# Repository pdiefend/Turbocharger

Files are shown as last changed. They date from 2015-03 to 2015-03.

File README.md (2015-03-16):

# Turbocharger
Turbocharger started as a Google Code Project and is in the process of being migrated to GitHub.
Farewell old friend.

The Turbocharger Arduino motor driver is a motor driver designed to amplify the abilities for Arduino robot control. This driver board includes encoder counters, an on-board motor driver, and serial communication headers to be as adaptable as possible for projects needing small motors with encoders.

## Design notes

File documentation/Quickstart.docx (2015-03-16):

# Turbocharger DC Motor Driver

# Features and Ratings

- Dual DC motor driver
  - ST-L298P Quad H-Bridge Motor Driver
  - Up to 48V motors and up to 2A per motor.
  - Up to 4A if both channels are used together
  - If 1A or less current is used, no heat sink or forced air cooling necessary
- Dual Quadrature Encoder Inputs
  - LS/CSI LS7366R-S Serial Encoder Counter from US Digital
  - 32-bit reconfigurable quadrature encoder counters
  - SPI enabled to reduce microcontroller utilization
- Designed for Arduino Uno
  - All communications are designed for 5V. A 3.3V board may be used if the pins are 5V tolerant. MISO (digital pin 12) is a 5V output from the encoder counters and will damage a 3.3V board.

# Caution:

Before making connections:

1. Ensure your power supply is ABLE to have the Negative DC Output connected to the common ground for the system. There are some power supplies in the wild that create a neutral->ground fault when the negative output from the supply is connected to ground. The driver will force a common ground to all supplies.
2. Add an appropriate sized fuse between the positive terminal of the power supply and the driver board. The driver is able to handle 3A for 100us, more than this will destroy the driver. Ask for help in fuse sizing if you are inexperienced.
3. If the Motor voltage is greater than 12V, make sure the Vin_enable jumper is cleared to prevent damage to the Arduino.

Finally, check all connectors for potential shorts before applying power.

# Pin Connections to Arduino

## Motor Driver Arduino Pin-out

Description | Arduino Pin Number
Channel A Direction | 7
Channel A PWM | 9
Channel A Current Sense | A3
Channel B Direction | 8
Channel B PWM | 10
Channel B Current Sense | A2

## Quadrature Encoder Arduino Pin-out

Description | Arduino Pin Number
MOSI | 11 | Pins 11-13 are SPI for the Arduino
MISO | 12 | and are handled in the SPI Library
SCK | 13 | Do not use the pins
Encoder Counter 1 Select | 4
Encoder Counter 2 Select | 5
Counter Enable | 6
!LFLAG with pull-up resistor | 2

# Pin Connections to Peripherals

Headers for easier connection to communication buses and other microcontroller functions have been provided for your convince. These headers include Two Wire Interface (TWI; also known as I2C), Serial Peripheral Interface (SPI), Universal Asynchronous Receiver/Transmitter (UART), and finally two analog input enabled pins that are available in servo-standard pin-outs.

## SPI

The SPI communication bus can support one additional peripheral (or more if you are experienced). The SPI bus is shared with the LS7366R-S Quadrature Encoder Counters. Digital Pin 3 has been made available for use as a chip select pin for this peripheral and is available on this header. Please note that pin 3 is arranged next to Vdd and Ground such that pin 3 can also be used apart from SPI with a servo-standard pin-out. This was done such that pin 3, which is an interrupt-enabled pin on the Arduino Uno, can be used for am interrupt-enabled limit switch.

## UART

The UART communication bus is broken out above the SPI bus on the board. This is the hardware UART for the Arduino with no flow control or reset. This can be used if a peripheral needs Serial communications and the UART is not being used to talk to the computer. When programming through the USB port peripherals connected to this header must be disconnected.

## TWI

PLEASE NOTE: SDA and SCL on the TWI header are labelled incorrectly and should be swapped.

The TWI has been made available for users who need the I2C communication protocol. On R3 Arduino Unos these pins are available on the digital side, but on R2 Arduino Unos these pins are only available with the analog input pins. In the interests of keeping this board inclusive, the TWI header is connected to Analog Pins A4 and A5. With this, if additional analog pins past A0 and A1 are needed and no I2C is needed, these pins can be directly used as analog inputs. Also, since all analog input pins are digital enabled as well, these pins can serve digital functions too.

## A0 & A1

A0 and A1 have been made available in servo-standard pin-outs. These pins were placed for easy addition of potentiometer feedback in case encoders are not needed or for easier use input. Additionally, these pins can be used for hobby servos, buttons, limit switches, or other low-pin count needs.

# Motor and Encoder Connections

## Motor Connections

The DC motors can be connected to the screw terminal blocks with 18-22AWG wire. Wire outside this size range may fit but will result in a poor connection. The channels can be connected in parallel for higher current capacity. The motor power inputs are designed with Vin and Ground where ground is common to the Arduino’s ground. Ensure your power supply can handle the DC negative output connected to earth ground.

## Encoder Connections

The encoder headers as labeled on the circuit board.

Description | PCB Label | Required
5V Encoder Power Supply | V | Yes
Encoder Channel A Output | A | Yes
Encoder Channel B Output | B | For quadrature applications
Encoder Index Output | I | For high repeatability
Encoder Power Supply Ground | G | Yes

# Default Jumper Configuration

At assembly the board is configured such that both current sense channels are connected to their respective pins and the Vin Enable Jumper is opened. If you application requires more pins than were made available in the auxiliary headers (UART, SPI, TWI, A1, A0), you can cut the trace on the bottom of the board between the solder jumper pads to disable one or both current sense channels for an additional two analog input enabled pins. If your motor power supply is between 7-12V, the Vin Enable jumper can be closed by bridging the solder pads and powering the Arduino from the motor power supply. Ensure this jumper is cleared before applying >12V to the motor Vin otherwise the Arduino’s power regulator will fail.

# Motor Driver Usage

The Motor Drivers are designed with2 pins to control each motor and one feedback pin for current sensing.

The Direction pin controls the direction the motor will turn and can be reversed by reversing the polarity of motor’s wires to the driver. The direction is set using the digitalWrite function.

The PWM output controls the motor’s speed and is controlled through the analogWrite function.

The current sensing is used through the analogRead function on the current sensing pin. The operational amplifier is set to a gain of 15:1 across the 0.15Ω sense resistor. This gives an output of 2.25V/1A of current through the motor. This gives an ratio of 460.35/A on the analog inputs. So an analog reading of 460 is about 1A and an analog reading of 920 is about 2A. See the attached MotorTest.ino file for an example of motor usage

# Encoder Counter Usage

The encoder counters are connected through SPI to the Arduino and can be accessed by pulling their respective chip select pins low. There is also a count enable pin that can be pulled low to disable the pulse counting functionality of the encoders. This would be used during setup while initializing everything then the counters would be enabled once the system is ready for them. A few functions were made to make usage of the encoder counters easier. A basic library is in the works but is not yet ready for external release. Please see the code called EncoderTest.ino to see an example of the encoder counters in use.

Turbocharger Alpha Release Quickstart Diefenderfer 2015

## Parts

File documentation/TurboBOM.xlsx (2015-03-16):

PCB no | part | Vendor | part No | cost / unit | quantity/prototype | quantity to order | sub total | Desc / Location / Comments | Percent of Cost
R1,6 | 14k 0603 | Digikey | P14.0KHCT-ND (http://www.digikey.com/product-detail/en/ERJ-3EKF1402V/P14.0KHCT-ND/198160) | 0.10 | 2 | 6 | 0.60
R2,5 | 1k 0603 | Digikey | MCT0603-1.00K-CFCT-ND (http://www.digikey.com/product-detail/en/MCT06030C1001FP500/MCT0603-1.00K-CFCT-ND/2607875) | 0.08 | 2 | 6 | 0.48 |  | 0.42%
R3,4 | 1M 0603 | Digikey | MCT0603-1.00M-CFCT-ND (http://www.digikey.com/product-detail/en/MCT06030C1004FP500/MCT0603-1.00M-CFCT-ND/2607877) | 0.08 | 2 | 6 | 0.48 |  | 0.42%
R7,8 | 0.15 0603 | Digikey | 408-1584-1-ND (http://www.digikey.com/product-detail/en/KRL1632E-M-R150-F-T5/408-1584-1-ND/3737766) | 0.54 | 2 | 6 | 3.24 |  | 2.81%
R9 | 10k 0603 | Digikey | MCT0603-10.0K-CFCT-ND (http://www.digikey.com/product-detail/en/MCT06030C1002FP500/MCT0603-10.0K-CFCT-ND/2607933) | 0.08 | 1 | 3 | 0.24 |  | 0.21%
C1-4 | 18pF 0603 (50V) | Digikey | 1276-2206-1-ND (http://www.digikey.com/product-detail/en/CL10C180FB8NNNC/1276-2206-1-ND/3890292) | 0.16 | 4 | 12 | 1.92 |  | 1.67%
C5-7,10,11 | 0.1uF 0603 (25V) | Digikey | 1276-1929-1-ND (http://www.digikey.com/product-detail/en/CL10B104JA8NNNC/1276-1929-1-ND/3890015) | 0.12 | 5 | 15 | 1.80 |  | 1.56%
C8,9 | 10uF "E" (50V) | Digikey | 5652129-1-ND (http://www.digikey.com/product-search/en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) | 0.34 | 2 | 6 | 2.04 |  | 1.77%
C12,13 | 1uF 0603 (10V) | Digikey | 490-1543-1-ND (http://www.digikey.com/product-detail/en/GRM188R61A105KA61D/490-1543-1-ND/587782) | 0.10 | 2 | 6 | 0.60 |  | 0.52%
Y1,2 | 40MHz oscil | Digikey | 535-11304-1-ND (http://www.digikey.com/product-search/en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) | 0.82 | 2 | 6 | 4.92 |  | 4.27%
U3 | L298p | Digikey | 497-3624-1-ND (http://www.digikey.com/product-search/en?pv7=2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) | 5.71 | 1 | 3 | 17.13 |  | 14.88%
U4 | LMV358SOIC | Digikey | LMV358MX/NOPBCT-ND (http://www.digikey.com/product-detail/en/LMV358MX%2FNOPB/LMV358MX%2FNOPBCT-ND/1010557) | 0.87 | 1 | 3 | 2.61 |  | 2.27%
U5,6 | Single Inverter | Digikey | 296-11599-1-ND (http://www.digikey.com/product-detail/en/SN74LVC1G04DBVR/296-11599-1-ND/385738) | 0.49 | 2 | 6 | 2.94 |  | 2.55%
B1,2 | Flyback Bridge | Digikey | MB1SCT-ND (http://www.digikey.com/product-detail/en/MB1S/MB1SCT-ND/2094421) | 0.45 | 2 | 6 | 2.70 |  | 2.35%
S1 | Button | Digikey | CKN9104CT-ND (http://www.digikey.com/product-search/en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) | 0.65 | 1 | 3 | 1.95 |  | 1.69%
U1,2 | LS7366R-S | US Digital | LS7366R-S (http://www.usdigital.com/products/interfaces/ics/lfls7366r-s) | 5.60 | 2 | 6 | 33.60 |  | 29.19%
Hdr pins | 1x40 pin hdr | Digikey | A26509-25-ND (http://www.digikey.com/product-detail/en/4-103741-0-25/A26509-25-ND/683410) | 1.41 | 2 | 6 | 8.46 |  | 7.35%
Pwr Con | Terminal Blocks | Digikey | ED10565-ND (http://www.digikey.com/product-detail/en/OSTVN06A150/ED10565-ND/1588866) | 1.47 | 1 | 3 | 4.41 |  | 3.83%
- | Arduino | ? | ? | 30.00 | 0 | 0 | 0.00 |  | 0.00%
PCB | - | OSH park | - | 25.00 | 0.33 | 1 | 25.00 | Less expensive | 21.72%
PCB | - | 4pcb | - | 33.00 | 0.00 | 0 | 0.00 | More expensive | 0.00%
Prototypes | 3 |  |  |  |  |  | 115.12
 |  |  |  |  |  | Cost/prototype | 38.37

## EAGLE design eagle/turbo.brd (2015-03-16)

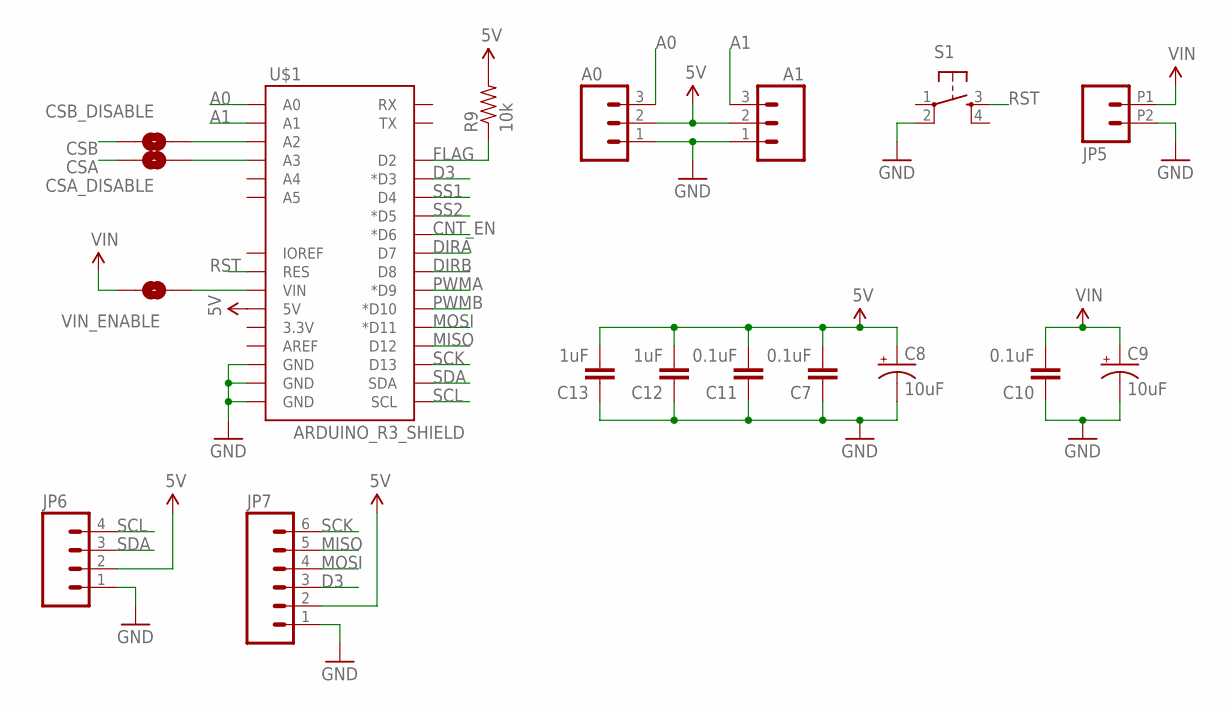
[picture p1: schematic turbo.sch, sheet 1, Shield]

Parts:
A0, A1: M03LOCK; 1X03_LOCK
C7, C10, C11: 0.1uF; 0603-CAP
C8, C9: 10uF; PANASONIC_C
C12, C13: 1uF; 0603-CAP
CSA_DISABLE: SOLDERJUMPERTRACE; SJ_2S-TRACE
CSB_DISABLE: SOLDERJUMPERTRACE; SJ_2S-TRACE
JP5: M022.54MM_SCREWTERM; 1X02_2.54_SCREWTERM
JP6: M04POLAR_LOCK; MOLEX-1X4_LOCK
JP7: M06POLAR_LOCK; MOLEX-1X6_LOCK
R9: 10k; 0603-RES
S1: TAC_SWITCHSMD; TACTILE_SWITCH_SMD
U$1: ARDUINO_R3_SHIELD; UNO_R3_SHIELD
VIN_ENABLE: SOLDERJUMPERNO; SJ_2S-NO

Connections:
5V: A0.2, A1.2, C7.2, C8.+, C11.2, C12.2, C13.2, JP6.2, JP7.2, R9.2, U$1.5V; also elsewhere on the board
A0: A0.3, U$1.A0
A1: A1.3, U$1.A1
CNT_EN: U$1.D6 (*D6); also elsewhere on the board
CSA: CSA_DISABLE.2; also elsewhere on the board
CSB: CSB_DISABLE.2; also elsewhere on the board
D3: JP7.3, U$1.D3 (*D3)
DIRA: U$1.D7; also elsewhere on the board
DIRB: U$1.D8; also elsewhere on the board
FLAG: R9.1, U$1.D2; also elsewhere on the board
GND: A0.1, A1.1, C7.1, C8.-, C9.-, C10.1, C11.1, C12.1, C13.1, JP5.P2 (2), JP6.1, JP7.1, S1.2, U$1.GND@0 (GND), U$1.GND@1 (GND), U$1.GND@2 (GND); also elsewhere on the board
MISO: JP7.5, U$1.D12; also elsewhere on the board
MOSI: JP7.4, U$1.D11 (*D11); also elsewhere on the board
unnamed: CSB_DISABLE.1, U$1.A2
unnamed: CSA_DISABLE.1, U$1.A3
unnamed: U$1.VIN, VIN_ENABLE.2
PWMA: U$1.D9 (*D9); also elsewhere on the board
PWMB: U$1.D10 (*D10); also elsewhere on the board
RST: S1.3, U$1.RES
SCK: JP7.6, U$1.D13; also elsewhere on the board
SCL: JP6.4, U$1.SCL
SDA: JP6.3, U$1.SDA
SS1: U$1.D4; also elsewhere on the board
SS2: U$1.D5 (*D5); also elsewhere on the board
VIN: C9.+, C10.2, JP5.P1 (1), VIN_ENABLE.1; also elsewhere on the board

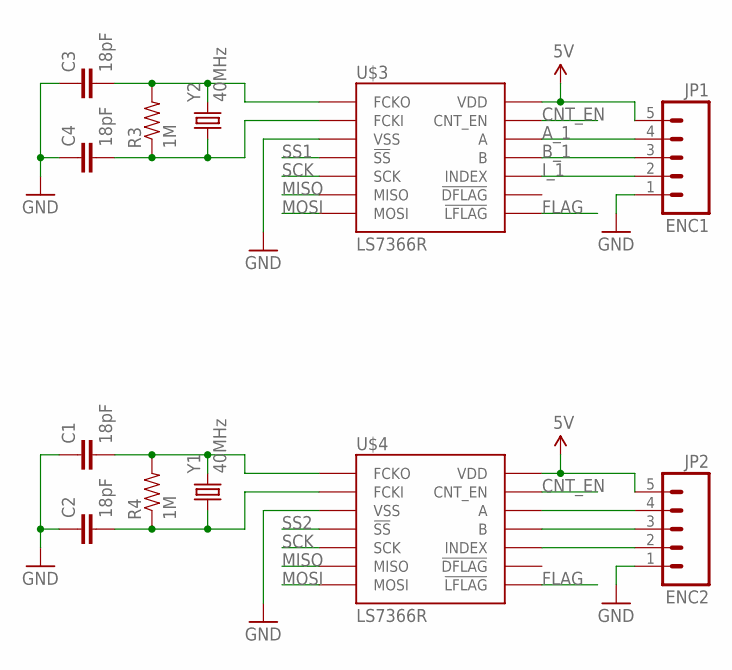
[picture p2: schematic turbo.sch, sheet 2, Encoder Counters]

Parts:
C1, C2, C3, C4: 18pF; 0603-CAP
JP1: ENC1; 1X05_LOCK
JP2: ENC2; 1X05_LOCK
R3, R4: 1M; 0603-RES
U$3, U$4: LS7366R; SOIC14
Y1, Y2: 40MHz; CRYSTAL-SMD-5X3

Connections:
5V: JP1.5, JP2.5, U$3.14 (VDD), U$4.14 (VDD); also elsewhere on the board
A_1: JP1.4, U$3.12 (A)
B_1: JP1.3, U$3.11 (B)
CNT_EN: U$3.13 (CNT_EN), U$4.13 (CNT_EN); also elsewhere on the board
FLAG: U$3.8 (!LFLAG), U$4.8 (!LFLAG); also elsewhere on the board
GND: C1.1, C2.1, C3.1, C4.1, JP1.1, JP2.1, U$3.3 (VSS), U$4.3 (VSS); also elsewhere on the board
I_1: JP1.2, U$3.10 (INDEX)
MISO: U$3.6 (MISO), U$4.6 (MISO); also elsewhere on the board
MOSI: U$3.7 (MOSI), U$4.7 (MOSI); also elsewhere on the board
unnamed: C3.2, R3.2, U$3.1 (FCKO), Y2.3 (2)
unnamed: C4.2, R3.1, U$3.2 (FCKI), Y2.1
unnamed: JP2.4, U$4.12 (A)
unnamed: JP2.3, U$4.11 (B)
unnamed: JP2.2, U$4.10 (INDEX)
unnamed: C1.2, R4.2, U$4.1 (FCKO), Y1.3 (2)
unnamed: C2.2, R4.1, U$4.2 (FCKI), Y1.1
SCK: U$3.5 (SCK), U$4.5 (SCK); also elsewhere on the board
SS1: U$3.4 (!SS); also elsewhere on the board
SS2: U$4.4 (!SS); also elsewhere on the board

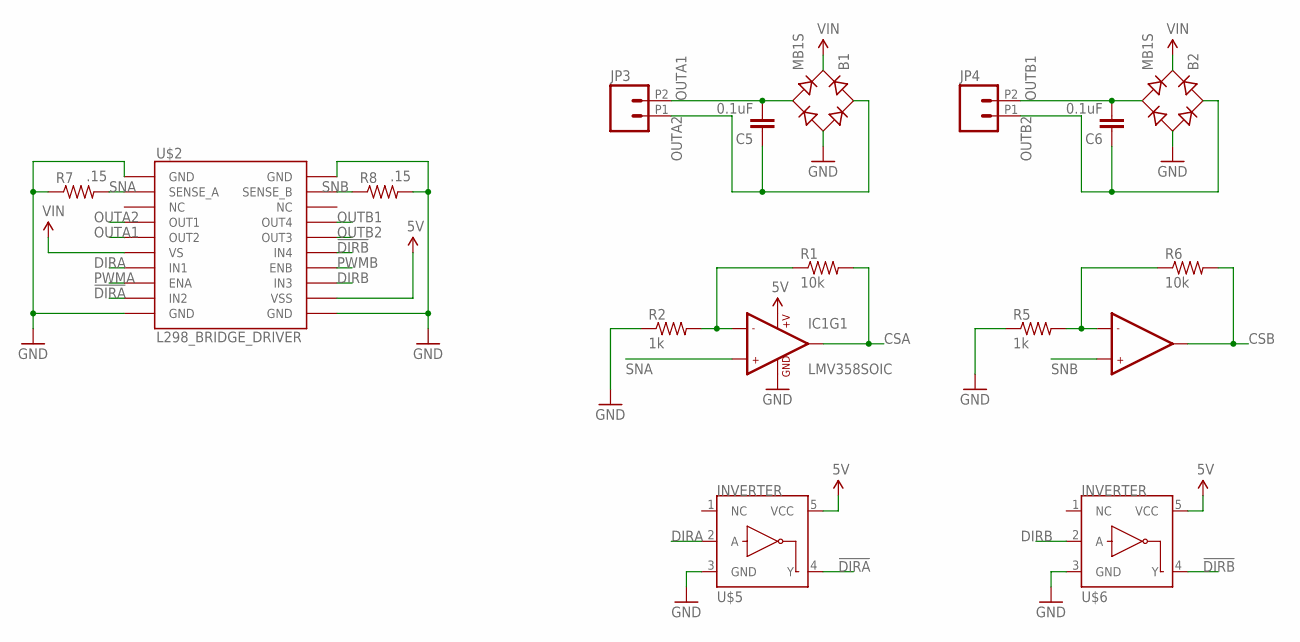
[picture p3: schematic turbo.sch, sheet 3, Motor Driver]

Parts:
B1, B2: MB1S; SOIC-4
C5, C6: 0.1uF; 0603-CAP
IC1: LMV358SOIC; SO08
JP3, JP4: M022.54MM_SCREWTERM; 1X02_2.54_SCREWTERM
R1, R6: 10k; 0603-RES
R2, R5: 1k; 0603-RES
R7, R8: .15; 1206
U$2: L298_BRIDGE_DRIVER; POWERSO20
U$5, U$6: INVERTER; SOT23-5

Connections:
5V: IC1.8 (+V), U$2.12 (VSS), U$5.5 (VCC), U$6.5 (VCC); also elsewhere on the board
!DIRA: U$2.9 (IN2), U$5.4 (Y)
!DIRB: U$2.15 (IN4), U$6.4 (Y)
CSA: IC1.1 (OUT1), R1.2; also elsewhere on the board
CSB: IC1.7 (OUT2), R6.2; also elsewhere on the board
DIRA: U$2.7 (IN1), U$5.2 (A); also elsewhere on the board
DIRB: U$2.13 (IN3), U$6.2 (A); also elsewhere on the board
GND: B1.-, B2.-, IC1.4 (GND), R2.1, R5.1, R7.1, R8.2, U$2.1 (GND), U$2.10 (GND), U$2.11 (GND), U$2.20 (GND), U$2.P$1 (GND), U$5.3 (GND), U$6.3 (GND); also elsewhere on the board
unnamed: IC1.6 (-IN2), R5.2, R6.1
unnamed: IC1.2 (-IN1), R1.1, R2.2
OUTA1: B1.~2 (AC2), C5.2, JP3.P2 (2), U$2.5 (OUT2)
OUTA2: B1.~1 (AC1), C5.1, JP3.P1 (1), U$2.4 (OUT1)
OUTB1: B2.~2 (AC2), C6.2, JP4.P2 (2), U$2.17 (OUT4)
OUTB2: B2.~1 (AC1), C6.1, JP4.P1 (1), U$2.16 (OUT3)
PWMA: U$2.8 (ENA); also elsewhere on the board
PWMB: U$2.14 (ENB); also elsewhere on the board
SNA: IC1.3 (+IN1), R7.2, U$2.2 (SENSE_A)
SNB: IC1.5 (+IN2), R8.1, U$2.19 (SENSE_B)
VIN: B1.+, B2.+, U$2.6 (VS); also elsewhere on the board

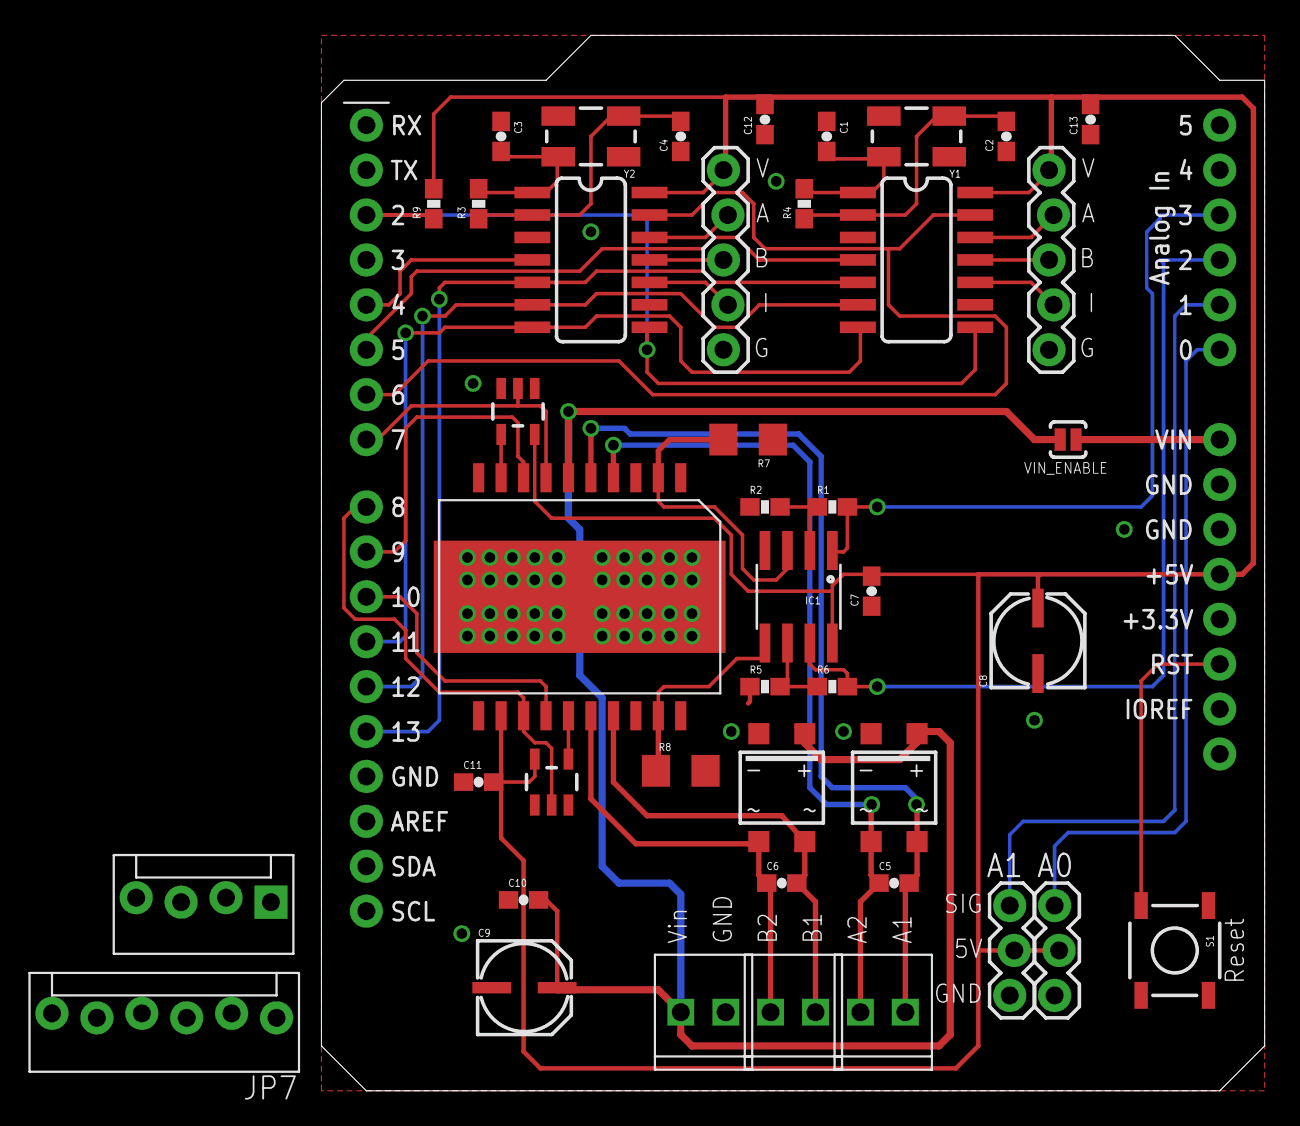
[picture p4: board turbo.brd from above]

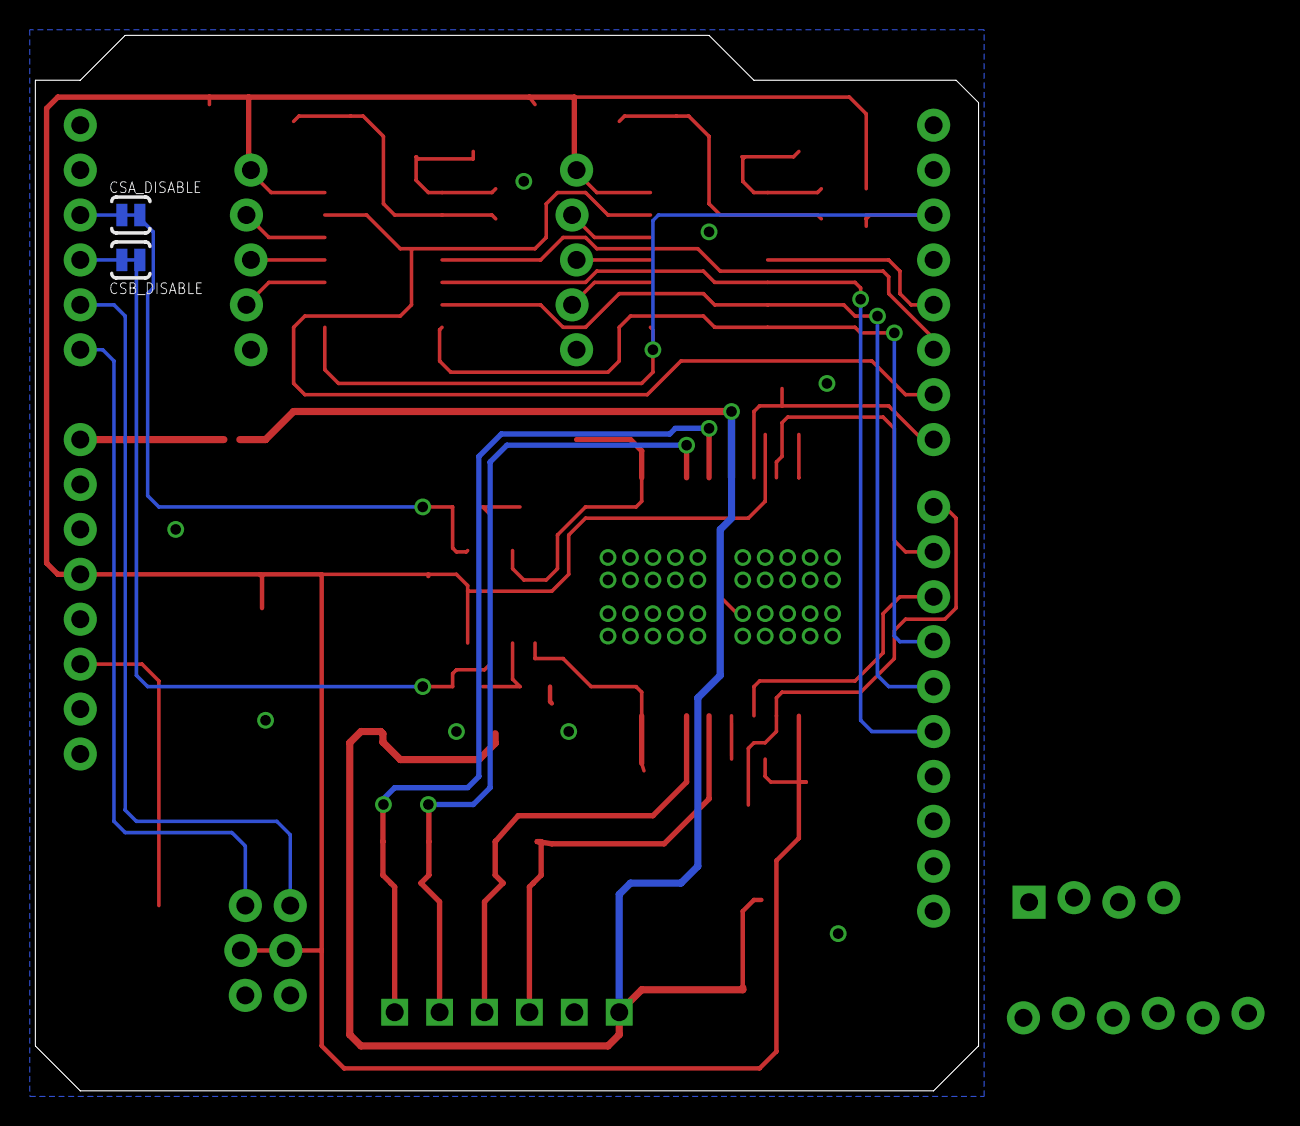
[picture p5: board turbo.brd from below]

Board: 2 copper layers, 53.3 x 59.7 mm, 46 parts (2 on the bottom side), 45 nets.

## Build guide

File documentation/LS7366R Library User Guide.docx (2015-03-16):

# LS7366R Library User Guide

This user guide will help describe the usage of the LS/CSI LS7366R-S Quadrature Encoder Counter library developed for Arduino. This library creates an object that makes interfacing with the encoder counter easier allowing for interface through simple functions rather than through bare-metal SPI programming.

# Constructors

### Default constructor

The default constructor for the LS7366R only requires two parameters and configures the encoder counter with the settings most widely applicable to most users. These default settings include:

- No Glitch Filter Clock Division (Clock Division = 1)
- Free Run Encoder Counting
- 2-Byte wide Counter Register
- 4x Quadrature counting.

The use of this constructor is:

LS7366R <object name>(<chip select pin>, <count enable pin>);

### Custom Configuration Constructor

The Custom Configuration Constructor allows the user full access to the mode registers at counter initialization. These open up options for the user for everything such as quadrature count resolution and counter width to interrupt configuration. The two 8-bit mode registers can be accessed through additional parameters to the constructor.

The use of this constructor is:

LS7366R <object name>(<chip select pin>, <count enable pin>, <MDR0 settings>, <MDR1 settings>);

The MDR Settings are set using the table below as a guide and the settings are used as such:

<MDR0 settings> = MDR0 X4_QUAD | FREE_RUN | DISABLE_IDX | ASYN_IDX | CLK_DIV_1

Leaving a field out of the settings list will cause that setting to be set to its default.

Table 1: MDR0 Settings. This register defaults to 0 at power up

MDR0 Settings
Section | Function | Constant
Counts per Quadrature Cycle | Non-Quadrature (A = clk, B = direction) | NON_QUAD
| x1 Quadrature Mode (1 count/cycle) | X1_QUAD
| X2 Quadrature Mode (2 counts/cycle) | X2_QUAD
| X4 Quadrature Mode (4 counts/cycle) | X4_QUAD
Count Mode | Free-Running count mode | FREE_RUN
| Single Cycle count mode* | SINGLE_CYCLE
| Range Limit mode* | RANGE_LIMIT
| Mod-n Count mode* | MOD_N_CNT
Index Mode | Disable index | DISABLE_IDX
| Load DTR into Counter on index | LOAD_CNTR
| Reset Counter on index | RST_CNTR
| Save Counter to OTR on index | LOAD_OTR
Index Synchronization | Asynchronous Index* | ASYN_IDX
| Synchronous Index* | SYN_IDX
Glitch Filter Clock Division | Filter Clock Division = 1 | CLK_DIV_1
| Filter Clock Division = 2 | CLK_DIV_2

*experienced users only; please refer to the LS7366R datasheet for more information

Bold values are the default values at power up

Table 2: MDR1 Settings. This register defaults to 0 at power up

MDR1 Settings
Section | Function | Constant
Counter Bytes | 4-byte counter mode | FOUR_BYTE
| 3-byte counter mode | THREE_BYTE
| 2-byte counter mode | TWO_BYTE
| 1-byte counter mode | ONE_BYTE
Counter Enable | Enable counter | ENABLE_CNT
| Disable counter | DISABLE_CNT
Index Interrupt | Interrupt on Index Pulse | FLAG_IDX
| Not Enabled | -
Compare Interrupt | Interrupt when Counter = DTR* | FLAG_CMP
| Not Enabled | -
Borrow Interrupt | Interrupt when Counter Underflows (0 -> max) | FLAG_BW
| Not Enabled | -
Carry-Over Interrupt | Interrupt when Counter overflows (max->0) | FLAG_CY
| Not Enabled | -

*experienced users only; please refer to the LS7366R datasheet for more information

Bold values are the default values

### Discussion of Settings

- Counts per Quadrature Cycle:

The counts per quadrature cycle setting determines how many events per quadrature cycle will increment (or decrement) the counter. In a quadrature cycle there are four events: both clock edges on both inputs.

  - On x4 Quadrature mode all four clock edges affect the counter.
  - On x2 Quadrature mode, only the rising edges (of falling edges, LS/CSI is not clear on which) will cause the counter to increment or decrement.
  - For x1 Quadrature mode, only a complete quadrature cycle will cause the counter to increment or decrement.
  - Finally, non-quadrature mode is used for non-quadrature inputs, where channel A is used to increment (or decrement) the clock and channel B determines whether the clock should be incremented or decremented.
- Count Mode:

The count mode controls how the counter runs through counter division and range limiting. The settings other than Free Run may provide useful in specific applications.

  - In Free-Run Count mode the counter will continuously count past overflows, underflows.
  - In Single-cycle count mode the counter will run operate normally until the counter overflows or underflows. At this point the counter will pause counting until handled.
  - In Range Limit mode the counter will operate the same as single cycle mode except the counter’s limits will be from 0 to the value stored in DTR and the count will resume once the direction resumes away from the boundary.
  - In Modulo-N count mode, this functionality is unknown. From the datasheet: (input count clock frequency is divided by a factor of (n+1), where n = DTR, in both up and down directions)
- Index Mode:

The Index mode determines the functionality of the Index pulse when it arrives. Note that this does not impact the interrupt setting for the index; rather it enables special settings for the index to be carried out asynchronously. These functions may prove helpful during homing depending on your application

  - The Disable Index setting does nothing on index pulse
  - The Load Counter setting will place the value in DTR into the counter on index pulse. The Reset Counter setting clears the Counter on index pulse
  - The Load OTR setting loads the value in the counter into the OTR register to be read by the readOTR() function.
- Index Synchronization:

This functionality is documented as existing in the datasheet but the true functionality is unknown.

  - Asynchronous Index
  - Synchronous Index: listed as overridden in non-quadrature mode.
- Glitch Filter Clock Division

This sets the clock division of the counter’s input glitch filter. A higher division factor will determine more precise readings at the cost of a lower maximum count frequency. Enable the higher clock division for high noise environments to provide better noise immunity.

  - Filter clock division = 1: 40MHz Glitch filter clock input
  - Filter clock division = 2: 20MHz Glitch filter clock input
- Counter Bytes:

This setting sets the number of bytes used in the counter. The full resolution is a 32-bit unsigned number, but not all applications require this much space or may desire the ability to count as high. Keep in mind that the Arduino Uno can handle 32-bit numbers but prefers 16-bit integers which will result in faster calculations.

  - Four Byte Mode enables the full 32-bit range of the counter 0->4.2 Billion
  - Three Byte Mode allows for a range of 0->16 Million
  - Two Byte Mode allows for a range of 0->65 thousand
  - One Byte Mode allows for a range of 0-> 256
- Counter Enable:

Enables or disables the counter in software. When single-cycle count mode is used this will resume counting. At this point this is allowed in the settings, but in the current implementation is not useful. In a future implementation this functionality will be better integrated.

  - Enable Counter: resumes counting if paused
  - Disable Counter: freezes counting if running
- Interrupts:

Interrupts will cause the LFLAG pin to pull its output low signaling an interrupt has occurred. Calling the readSTR() function will return the status register and clear the interrupt. The LFLAG interrupt is an open-drain latching interrupt which should be connected to an interrupt-enabled pin with a pull-up resistor. See the readSTR() documentation below for more information on retrieving the interrupt cause.

  - Index Interrupt: Interrupt on an index pulse
  - Index Compare Interrupt: Interrupt when the counter equals the value in DTR
  - Borrow Interrupt: Interrupt when the counter underflows or goes below 0
  - Carry-over Interrupt: Interrupt when the counter overflows or goes above its max

# Functions

### unsigned long readEncoder()

Reads the encoder’s current count and returns the result as an unsigned long

### void clearEncoder()

Resets the Encoder’s current count to 0

### void enableEncoder()

Pulls the counter’s count enable pin high to resume counting after being paused or after power up

### void disableEncoder()

Pulls the counter’s count enable pin low to pause counting

### void writeDTR(unsigned long <value to write>)

Writes the parameter value to the DTR register for use with the Compare Interrupt, Range Limit counting, Mod-N counting, and presetting the counter register on index pulse

### byte readSTR()

Reads then clears the status register and returns the status register as the return value. This function also clears the LFLAG latching interrupt. The table below discusses bit masks for the Status register for if statements.

Name | Description | Bit Mask Name
Carry Latch | Latch set when CNTR overflows | CY_MASK
Borrow Latch | Latch set when CNTR underflows | BW_MASK
Compare Latch | Latch set when CNTR = DTR | CMP_MASK
Index Latch | Latch set by Index Pulse | IDX_MASK
Count Enabled | 0: count disabled, 1: count enabled | CEN_MASK
Power Loss Indicator | 1: if status has not been cleared since last power up | PLS_MASK
Count Direction | 0: count down, 1: count up | UD_MASK
Sign Bit | Mostly Unknown at this time | S_MASK

Keep in mind that multiple bits can be set at once. The above bits masks can be used as follows:

If (<object name>.readSTR() & CY_MASK) {

// code for when carry-over has occurred

}

An interrupt that was triggered by the LS7366R can be cleared through reading the status register. If multiple interrupts are enabled ensure you check all applicable bits as many may have triggered before you read the register. Do not call this function in an ISR.

### unsigned long readOTR()

Coming soon

### void setCounter(unsigned long)

Coming soon

Turbocharger Alpha Release LS7366R Library Diefenderfer 2015

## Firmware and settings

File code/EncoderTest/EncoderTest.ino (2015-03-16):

#include <SPI.h>

#define SS1 4
#define SS2 5
#define CNT_EN 6

// These hold the current encoder count.
signed long encoder1count = 0;
signed long encoder2count = 0;

void initEncoders() {

  // Set slave selects as outputs
  pinMode(SS1, OUTPUT);
  pinMode(SS2, OUTPUT);

  pinMode(CNT_EN, OUTPUT);

  // Raise select pins
  // Communication begins when you drop the individual select signsl
  digitalWrite(SS1, HIGH);
  digitalWrite(SS2, HIGH);
  digitalWrite(CNT_EN, HIGH);

  SPI.begin();

  // Initialize encoder 1
  //    Clock division factor: 0
  //    Negative index input
  //    free-running count mode
  //    x4 quatrature count mode (four counts per quadrature cycle)
  // NOTE: For more information on commands, see datasheet
  digitalWrite(SS1, LOW);       // Begin SPI conversation
  SPI.transfer(0x88);                       // Write to MDR0
  SPI.transfer(0x03);                       // Configure to 4 byte mode
  digitalWrite(SS1, HIGH);      // Terminate SPI conversation

  // Initialize encoder 2
  //    Clock division factor: 0
  //    Negative index input
  //    free-running count mode
  //    x4 quatrature count mode (four counts per quadrature cycle)
  // NOTE: For more information on commands, see datasheet
  digitalWrite(SS2, LOW);       // Begin SPI conversation
  SPI.transfer(0x88);                       // Write to MDR0
  SPI.transfer(0x03);                       // Configure to 4 byte mode
  digitalWrite(SS2, HIGH);      // Terminate SPI conversation
}

long readEncoder(int encoder) {

  // Initialize temporary variables for SPI read
  unsigned int count_1, count_2, count_3, count_4;
  long count_value;

  switch (encoder) {
    case 1:
      digitalWrite(SS1, LOW);     // Begin SPI conversation
      break;
    default: // If it was not 1, it must be 2...
      digitalWrite(SS2, LOW);     // Begin SPI conversation
      break;
  }
  
  SPI.transfer(0x60);                     // Request count
  count_1 = SPI.transfer(0x00);           // Read highest order byte
  count_2 = SPI.transfer(0x00);
  count_3 = SPI.transfer(0x00);
  count_4 = SPI.transfer(0x00);           // Read lowest order byte

  digitalWrite(SS1, HIGH);    // Terminate SPI conversation
  digitalWrite(SS2, HIGH);    // Terminate SPI conversation

  // Calculate encoder count
  count_value = (count_1 << 8) + count_2;
  count_value = (count_value << 8) + count_3;
  count_value = (count_value << 8) + count_4;

  return count_value;
}

void clearEncoderCount() {

  // Set encoder1's data register to 0
  digitalWrite(SS1, LOW);     // Begin SPI conversation
  // Write to DTR
  SPI.transfer(0x98);
  // Load data
  SPI.transfer(0x00);  // Highest order byte
  SPI.transfer(0x00);
  SPI.transfer(0x00);
  SPI.transfer(0x00);  // lowest order byte
  digitalWrite(SS1, HIGH);    // Terminate SPI conversation

  delayMicroseconds(100);  // provides some breathing room between SPI conversations

  // Set encoder1's current data register to center
  digitalWrite(SS1, LOW);     // Begin SPI conversation
  SPI.transfer(0xE0);
  digitalWrite(SS1, HIGH);    // Terminate SPI conversation

  // Set encoder2's data register to 0
  digitalWrite(SS2, LOW);     // Begin SPI conversation
  // Write to DTR
  SPI.transfer(0x98);
  // Load data
  SPI.transfer(0x00);  // Highest order byte
  SPI.transfer(0x00);
  SPI.transfer(0x00);
  SPI.transfer(0x00);  // lowest order byte
  digitalWrite(SS2, HIGH);    // Terminate SPI conversation

  delayMicroseconds(100);  // provides some breathing room between SPI conversations

  // Set encoder2's current data register to center
  digitalWrite(SS2, LOW);     // Begin SPI conversation
  SPI.transfer(0xE0);
  digitalWrite(SS2, HIGH);    // Terminate SPI conversation
}


void setup() {
  Serial.begin(115200);      // Serial com for data output

  initEncoders();       Serial.println("Encoders Initialized...");
  clearEncoderCount();  Serial.println("Encoders Cleared...");
}

void loop() {
  delay(500);

  // Retrieve current encoder counters
  encoder1count = readEncoder(1);
  encoder2count = readEncoder(2);
  
  Serial.print("Enc1: "); Serial.print(encoder1count);
  Serial.print(" Enc2: "); Serial.print(encoder2count);
  Serial.println();
  
}

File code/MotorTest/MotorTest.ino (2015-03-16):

#define DIRA 7
#define DIRB 8
#define PWMA 9
#define PWMB 10
#define CSA A3
#define CSB A2

void setup(){
  Serial.begin(115200);

  pinMode(DIRA, OUTPUT);
  pinMode(DIRB, OUTPUT);
  pinMode(PWMA, OUTPUT);
  pinMode(PWMB, OUTPUT);

  digitalWrite(DIRA, LOW);
  digitalWrite(DIRB, LOW);
  digitalWrite(PWMA, LOW);
  digitalWrite(PWMB, LOW);

  pinMode(A3, INPUT);
  pinMode(A4, INPUT);

  Serial.println("Begin in 1s");
  delay(1000);
}

void loop(){
  digitalWrite(DIRA, HIGH);
  Serial.println("Forward Ramp Up");
  for(int i = 0; i < 255; i++){
    analogWrite(PWMA, i);
    delay(10); 
  }

  Serial.println("Forward Hold");
  analogWrite(PWMA, 255);
  delay(1000);
  Serial.println(analogRead(CSA));
  delay(1000);

  Serial.println("Forward Ramp Down");
  for(int i = 255; i > 0; i--){
    analogWrite(PWMA, i);
    delay(10); 
  }

  digitalWrite(PWMA, LOW);
  Serial.println("Halt");
  delay(2000);  



  digitalWrite(DIRA, LOW);
  Serial.println("Backward Ramp Up");
  for(int i = 0; i < 255; i++){
    analogWrite(PWMA, i);
    delay(10); 
  }

  Serial.println("Backward Hold");
  analogWrite(PWMA, 255);
  delay(1000);
  Serial.println(analogRead(CSA));
  delay(1000);

  Serial.println("Backward Ramp Down");
  for(int i = 255; i > 0; i--){
    analogWrite(PWMA, i);
    delay(10); 
  }

  digitalWrite(PWMA, LOW);
  Serial.println("Halt");
  delay(2000);  
}

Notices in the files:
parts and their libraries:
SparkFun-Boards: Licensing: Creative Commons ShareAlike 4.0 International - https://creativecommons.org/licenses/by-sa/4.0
